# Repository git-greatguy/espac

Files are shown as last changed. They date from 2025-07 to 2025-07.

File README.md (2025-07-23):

# ESPAC Smart Wifi Thermostat

This piece of software is a thermostat, based on esphome / arduino, that drive airton AC's throught its available serial port.

"ESPAC" is available under two edition : "Wifi" (standalone webserver) and "Home assistant" with better integration.

It is a substitution to closed source "ACW02" wifi module / ref 409729, commonly sold with airton air conditioner, with my own QOL functionnalities added.

## Global Features

- Should Works with most Airton AC ( at least ref : 409934, 409935, 409936 ) 
- Automation : Automatic double setpoint thermostat
- Care : Timer protection - ensure compressor minimal runtime when kicked in.
- Controls : Modes (heat, cold...), flaps position, fan speed, screen on/off, beeper on/off
- Privacy : Lan communication through wifi (web server, home assistant api or both)
- Home Assistant thermostat card (Home Assistant edition) 
- Customizable temperature sensor source (Home Assistant edition)

## Actual state of project

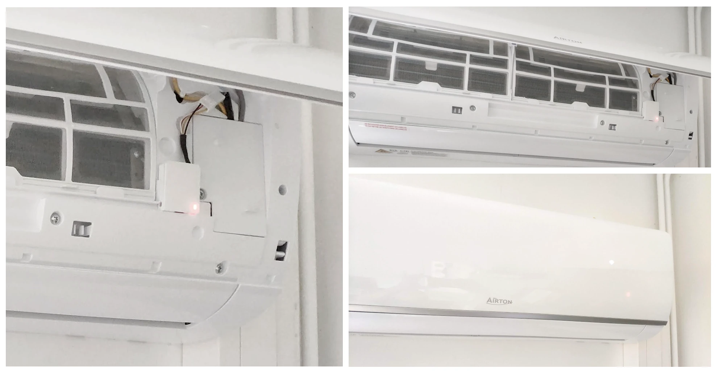
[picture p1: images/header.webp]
espac unit
 

```
<proto
 data-measurement="mm"
 height="44"
 width="36"
 alt="9"
 weigth="14" unit="g"
 />
```
> It's small, light and easy to fit under the hood.
 
## Appendix

- [Start Making your own](#start-making-your-own)
  - [What you need](#what-you-need)
  - [Pinout and Soldering](#pinout-and-soldering)
  - [3D model case to print](#3d-model-case-to-print)
- [Home Assistant edition](#home-assistant-edition)
- [Wifi edition](#wifi-edition)
- [Installation and first start](#installation-and-first-start)
- [Missing features to implement](#missing-features-to-implement)
- [Support project](#support-project)
- [Order wifi edition unit](#order-wifi-edition-unit)

## Start making your own

  ### What you need

| Hardware  |  | |
| --- | --- | --- |
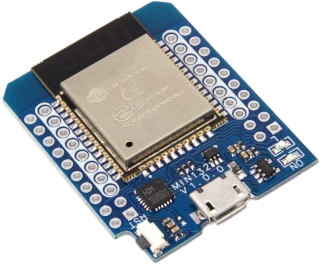
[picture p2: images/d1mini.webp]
d1mini
| ESP32 D1 mini  | Required |   |
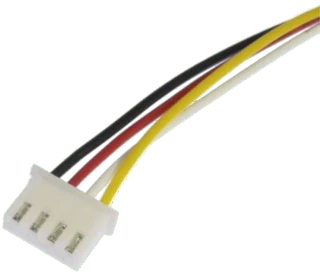
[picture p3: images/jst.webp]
| JST connector - 4 pins - 2.54mm pitch  | Required |   |
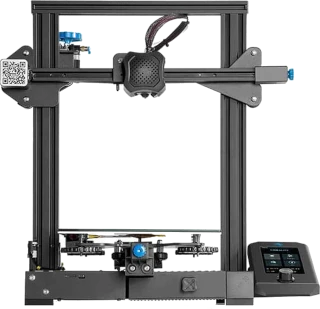
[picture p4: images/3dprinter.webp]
| 3D Printer  | Optionnal |   |

That's it !

Of course, you also need a soldering iron and some tin to complete the job !

 ### Pinout and Soldering

  This is how to solder the jst connector's wires on the d1 mini.
  
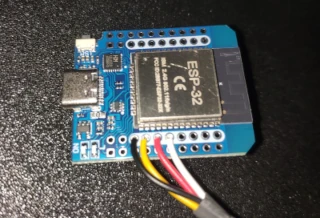
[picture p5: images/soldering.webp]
Pinout & soldering
  
  
  | Wire | GPIO | Wire color D1 side | wire color AC side |
  | ------------- | ------------- | ------------- | ------------- |
  | 5V | VCC | Black | Red | 
  | Ground | GND | Yellow | Purple |
  | TX | 16 | Red | Blue |
  | RX | 17 | White | Green |

 ### 3D Model case to print
  Small form factor case. Stl file avaiblable [here](/3d_case/espac_case_final.stl)  

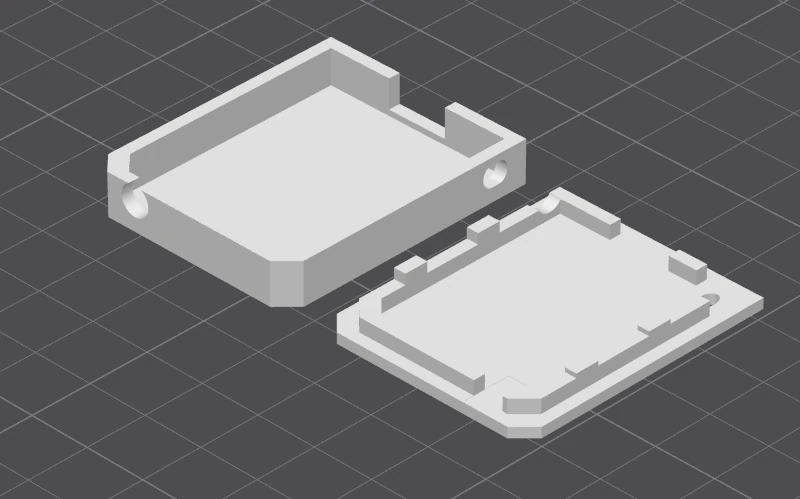
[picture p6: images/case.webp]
case 3d model
  

## Home Assistant edition
 Home assistant edition has to be flashed on your own with your Home assistant api key. 

  ### Setup
   - Configure a new esphome device with your api, ota, wifi informations.
   - Add yaml configuration avaible [here](/home_assistant_edition/espac_configuration.yaml) to your device configuration.
   - Optional configuraion for an external temperature sensor. Please check yaml configuration.  
   - Compile and Flash firmware with usb cable.
   - Plug device on indoor AC unit. [see](#installation-and-first-start)
   - Device should be available in Home Assistant after soime time, then add it to you devices. 
   - Add a new card to your Home Assistant dashboard. Example thermostat configuration card is available [here](/home_assistant_edition/thermostat_card).

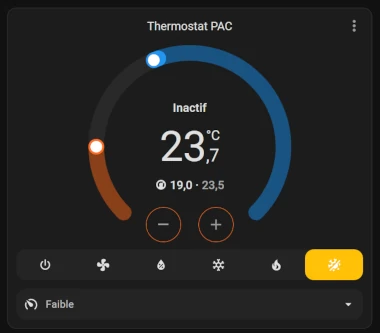
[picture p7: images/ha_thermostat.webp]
home assistant thermostat
   

   > Home Assistant Thermostat Card
     
## Wifi edition

  Wifi edition is web based thermostat, without esphome features, directly connected to your local network through your home wifi.
  You can configure your thermostat with any browser on any device connected to your local network.

  ### Setup
   - Download firmware from release page
   - Flash firmware with usb cable
   - Plug on ac unit ! [see](#installation-and-first-start)
   - Connect to device temporary wifi Access Point, name "ESPAC", password "12345678".
   - Open webpage http://192.168.1.4/, select your wifi network ssid, enter your wifi password, submit !
   - Device will then connect to your network and get an internal ip adressfrom your DHCP.
   - Connect to device with either mobile or desktop browser.

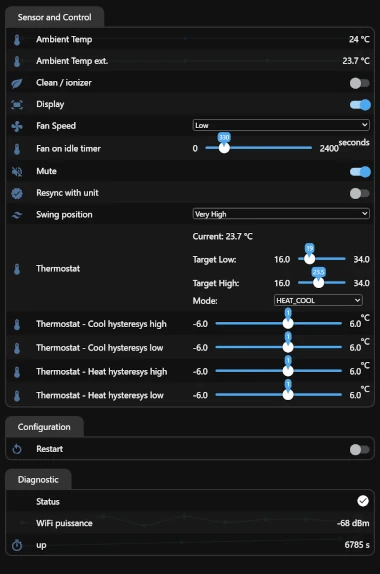
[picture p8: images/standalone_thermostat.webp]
standalone thermostat
  
  
  > Standalone controls web interface

## Installation and first start
 
 It's as simple as to plug 4 pin jst connector. Use some double tape to stick it to the main unit body. then :
  - Red LED must light on immediatly. If not, press wifi button on your remote control.
  - Wait until espac take control on device over serial. Blue light should blink at least once. If erverything is ok, it should kick in "fan_only" mode. ( can take up to 1 min )

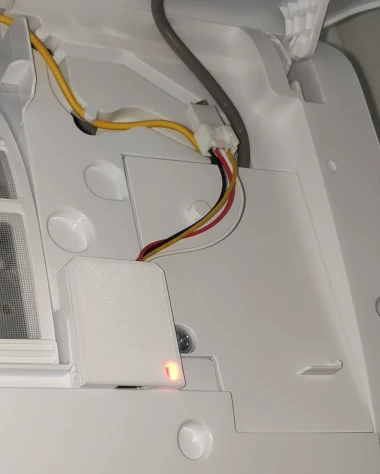
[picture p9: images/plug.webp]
plug jst connector

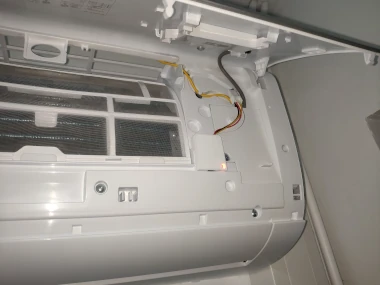
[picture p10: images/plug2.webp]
plug jst connector 2


> [!WARNING]
> Main voltage hazard. Please, security first ! if you dont know how to deal with main voltage and breaker, call an electrician.

## Missing features to implement
  - Eco mode
  - Timer
  - Humidity percent setting for "huimidity based" mode. (should be default 60% in actual state) 
  - Automatic profile switching ( ie day / night )

## Support Project

if you want to support hard work, you can [buy me a beer](https://buymeacoffee.com/dohmotik)

Thanks for your support !

## Order "wifi edition" unit

  You can order a "wifi edition" unit from [buymeacoffee](https://buymeacoffee.com/dohmotik/e/436984)
  
  All units are shipped "ready to plug" flashed with "wifi edition" firmware, also available on release page. 
  
  It can be flash with any edition you want though its usb-c port.

  Thanks.

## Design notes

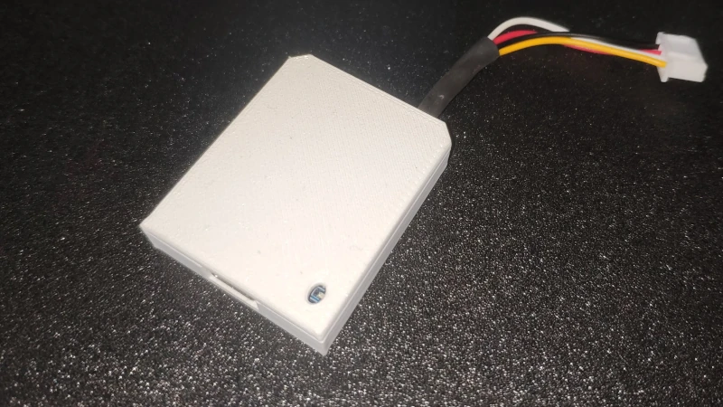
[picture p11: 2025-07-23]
images/final_product.webp

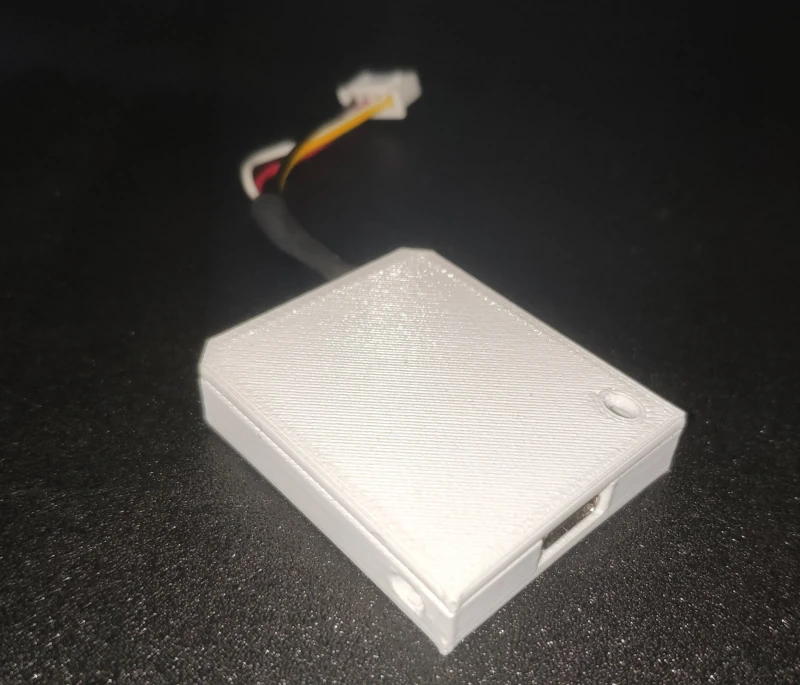
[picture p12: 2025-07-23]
images/final_product2.webp

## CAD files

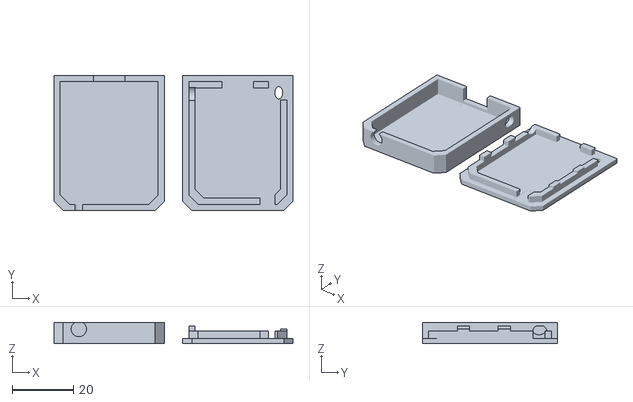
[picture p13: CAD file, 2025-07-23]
3d_case/espac_case_final.stl
78.0 x 44.0 x 7.00

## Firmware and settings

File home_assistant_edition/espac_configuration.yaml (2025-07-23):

esphome:
  name: espac
  friendly_name: ESPAC - Smart wifi thermostat

esp32:
  board: esp32dev
  framework:
    type: arduino

api:
  encryption:
    key: ""

ota:
  - platform: esphome
    password: ""

logger:
  tx_buffer_size: 1024
  level: DEBUG
  logs:
    sensor: ERROR
    component: ERROR
    switch: ERROR
    select: ERROR
    esp32.preferences: ERROR

substitutions:
  ambient_sensor: internal_temp # or internal_temp if no ext sensor
  ext_sensor:  null.null # or sensor.my_ext_temp_sensor for home assistant sensor
  hide_ext_sensor: true # hide external sensor
  hide_debug: true # hide /show debug sensor
  hide_hyst: false # hide / show hysteresys sensor

wifi:
  ssid: !secret wifi_ssid
  password: !secret wifi_password
  ap:
    ssid: "ESPAC"
    password: "12345678"
captive_portal:
  
web_server:
  port: 80
  version: 3
  log: true
  ota: False
  sorting_groups:
    - id: settings_group
      name: "Settings"
      sorting_weight: -3
    - id: hyst_group
      name: "Hysteresys"
      sorting_weight: -2
    - id: command_group
      name: "Command"
      sorting_weight: -1
    - id: diag_group
      name: "Diagnostic"
      sorting_weight: 0

uart:
  id: ser1
  tx_pin: GPIO16
  rx_pin: GPIO17
  baud_rate: 9600
  rx_buffer_size: 1024
  debug:
    direction: BOTH
    dummy_receiver: true
    sequence:
    - lambda: |-
        if (direction == UART_DIRECTION_RX) {
          if (bytes.size() >= 34) {
            id(internal_temp).publish_state(bytes[10]);
            if(id(dsync).state == 1) return;

            id(ac_state).publish_state(bytes[13]); 
            id(fan_state).publish_state(bytes[13]);
            if(id(ctemp_state).state == 0) id(ctemp_state).publish_state(bytes[14]);
            id(oscv_state).publish_state(bytes[15]);
            id(osch_state).publish_state(bytes[15]);
            id(unit_state).publish_state(bytes[16]);
            switch((int)bytes[16]){ //bad but should work
              case 4:
                if(id(screen_sw).state) id(screen_sw).turn_off();
                if(id(clean_sw).state) id(clean_sw).turn_off();
                break;
              case 68:
                if(!id(clean_sw).state) id(clean_sw).turn_on();
                if(id(screen_sw).state) id(screen_sw).turn_off();
                break;
              case 136:
                if(!id(screen_sw).state) id(screen_sw).turn_on();
                if(id(clean_sw).state) id(clean_sw).turn_off();
                break;
              case 200:
                if(!id(screen_sw).state) id(screen_sw).turn_on();
                if(!id(clean_sw).state) id(clean_sw).turn_on();
                break;
            }
            if((((int)bytes[15] & 0xF0)/16)==1){
              if(!id(swing_horizontal).state) id(swing_horizontal).turn_on();
            }
            id(reset_thermostat).execute(); //set default to fan_only mode on boot
            id(apply).turn_off();
            id(dsync).publish_state(1);
            id(LED).publish_state(true);
          }
        }

time:
  - platform: sntp
    id: refresh_thermostat
    on_time: 
      - seconds: /30
        then:
          - lambda: id(external_temp).publish_state(id(external_temp).state);

  - platform: sntp
    id: idletooff
    on_time: 
      - seconds: /10
        then:
          - lambda: |-
              if(id(dsync).state == 0 || id(tsidle).state == 0) return;
              if(id(esp_thermostat).action != 4){ // not idle mode so abort timely auto off
                id(tsidle).publish_state(0);
                return;
              }
              time_t timestamp = ::time(&timestamp);
              if(timestamp-id(tsidle).state > id(fanidletimer).state){ // more than 2400s idle set to off, should put fan off until next action event
                auto call_mode = id(ac_mode_consigne).make_call();
                call_mode.set_option("Off");
                call_mode.perform();
                id(tsidle).publish_state(0);
                id(writecommand).publish_state(0);
              }
          - script.execute:
              id: set_temp_regulation
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

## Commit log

2025-07-23 1.00 commit
    [espac_case_final.stl]
2025-07-23 1.0.1
    Sorting, grouping Sensors
2026-10-11 Preserve UTF-8 temperature units and documentation
